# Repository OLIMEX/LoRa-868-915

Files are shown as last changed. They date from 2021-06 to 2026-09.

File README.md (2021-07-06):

# LoRa868 / LoRa915 / MOD-LoRa868 / MOD-LoRa915

LoRa modules with SX1276 modem from Semtech.

Product page: https://www.olimex.com/Products/IoT/LoRa/LoRa868/open-source-hardware

Product page: https://www.olimex.com/Products/IoT/LoRa/LoRa915/open-source-hardware

Product page: https://www.olimex.com/Products/IoT/LoRa/MOD-LoRa868/open-source-hardware

Product page: https://www.olimex.com/Products/IoT/LoRa/MOD-LoRa915/open-source-hardware

## License
* Hardware design is released under CERN OHL v1.2 license
* Software is released under GPL3 License
* Documentation is released under CC BY-SA 3.0

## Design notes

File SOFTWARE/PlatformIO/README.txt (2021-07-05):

Demo project for 2xMOD-LORA and 2xOlimexino-2560 made for PlatformIO environment with Arduino plugin.

Load the whole folder "LoRaPingPong" in PlatformIO, remember to edit platformio.ini to fit your USB port and board.

The code will ping-pong data between at least two boards. Refer to main.cpp.

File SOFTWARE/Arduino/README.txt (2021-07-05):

The Olimex LoRa board had been tested successfully with the Arduino library "LoRa" by Sandeep Mistry, just find it and install it from the Arduino library manager. Refer to the picture in this folder.

Other libraries and software that support the SX1276 chip should work well with the boards too.

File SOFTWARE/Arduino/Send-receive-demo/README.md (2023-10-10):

Demo software for Olimex MOD-LoRa868-ANT/MOD-LoRa868-EANT and Olimex ESP32-EVB

Demo uses sandeepmistry's LoRa library and examples:

https://github.com/sandeepmistry/arduino-LoRa

Configuration for ESP32-EVB comes with ESP32 package for Arduino:

https://github.com/espressif/arduino-esp32

Required hardware:

- Two (2) MOD-LoRa868-ANT/MOD-LoRa868-EANT modules

- Two (2) ESP32-EVB boards

- Two (2) micro USB cables

Remember LoRa modules would NOT work without an external antenna!

Required software:

- Arduino IDE, get it from here:

https://www.arduino.cc/en/software

- ESP32 package for Arduino IDE, install it following this advice:

https://espressif-docs.readthedocs-hosted.com/projects/arduino-esp32/en/latest/installing.html

- Arduino LoRa library by Sandeep Mistry, install following the advice here:

https://github.com/OLIMEX/LoRa-868-915/tree/main/SOFTWARE/Arduino

Once set, remember to select Olimex ESP32-EVB from board selector and the COM port where 
the board is located.

Each MOD-LoRa868 gets connected directly to the UEXT of each of the 
ESP32-EVB boards. One couple gets programmed with LoRaSender.ino,
the other with - LoRaReceiver.ino.

Connect both boards to free USB ports.

Open serial terminal software (like PuTTY) on each board's virtual COM port. Baud is 115200.

One board sends hello packets in a 1 second interval. 

The other receives packets "hello #number" and reports signal strength.

Refer to picture test.ping.

The demo can be used with MOD-LoRa915-ANT or other boards with SPI:

- If you decide to use MOD-LoRa915-ANT instead, you need to edit the code,
change LoRa.begin(868E6) to LoRa.begin(915E6) in both .ino files.

- If you decide to use another board that has free SPI make sure to change
defines at start so that it corresponds to your board; notice that
if MISO, MOSI, CLK are different to what is defined for your board
you might need to edit the library.

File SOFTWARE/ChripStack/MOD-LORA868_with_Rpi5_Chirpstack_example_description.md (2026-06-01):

# MOD-LORA868 + ChirpStack Demo Guide

## Overview

This guide demonstrates a complete LoRaWAN uplink/downlink test using an **Olimex MOD-LORA868** node and a **ChirpStack** network server running on a **Raspberry Pi 5** with an **LR1302 Gateway HAT (868 MHz)**.

The gateway image comes pre-configured with ChirpStack, a device profile (LoRaWAN 1.1.0, ABP, Class A, EU868, RP002-1.0.5), and matching ABP keys — so you can focus on the node side and start testing right away.

## Hardware Required

**Gateway side:**
- Raspberry Pi 5
- LR1302 LoRa Gateway HAT (868 MHz) — with its 868 MHz antenna
- MicroSD card (8 GB or larger)
- Ethernet cable (for network access)

**Node side:**
- ESP32-C6-DevKit-LiPo
- MOD-LORA868 (plugged into the UEXT connector)
- 868 MHz antenna for MOD-LORA868
- USB-C cable

> **⚠️ Important:** Always attach the 868 MHz antenna to MOD-LORA868 before powering on. Transmitting without an antenna can damage the RF stage.

## Gateway Setup

1. Download `rpi_chirpstack_lora_868_example.zip` from here: https://ftp.olimex.com/LoRa/rpi_chirpstack_lora_868_example.zip and extract the image file.
2. Write the image to a MicroSD card using [Raspberry Pi Imager](https://www.raspberrypi.com/software/) or [balenaEtcher](https://etcher.balena.io/).
3. Mount the LR1302 Gateway HAT on the Raspberry Pi 5 and connect its 868 MHz antenna.
4. Insert the MicroSD card and connect the Pi to your local network via Ethernet.
5. Power on the Raspberry Pi and wait about a minute for all services to start.

**Accessing the gateway:**

- **SSH:** `ssh olimex@olimexpi.local` (password: `olimex`)
- **ChirpStack Web UI:** open [http://olimexpi.local:8080/](http://olimexpi.local:8080/) in a browser (login: `admin` / `admin`)

The image comes with the gateway, device profile, and a test device already configured — no additional ChirpStack setup is needed.

## Node Firmware Setup

### Requirements

- Arduino IDE 2.3.7 (or compatible)
- ESP32 board package installed (with ESP32-C6 support)
- [RadioLib](https://github.com/jgromes/RadioLib) library v7.5.0

### Board Settings

In Arduino IDE, select:

- **Board:** ESP32C6 Dev Module
- **USB CDC On Boot:** Disabled
- All other settings can remain at their defaults.

### Upload

1. Plug MOD-LORA868 into the UEXT connector on the ESP32-C6-DevKit-LiPo.
2. Attach a 868 MHz antenna to MOD-LORA868.
3. Connect the board to your PC via the USB-C port labeled **USB-UART1** — this is also where the Serial Monitor output will appear.
4. Open the sketch in Arduino IDE, compile and upload.
5. Open Serial Monitor at **115200 baud**.

## Running the Test

After upload you should see:

```
START
Initializing radio... OK

╔════════════════════════════════════════╗
║      MOD-LORA868 Test v1.2             ║
╚════════════════════════════════════════╝
  Mode: ABP (no Join)
  NVS persistence: ENABLED
  Press ENTER or button to run test
  Type 'R' + ENTER to reset session
```

Press **ENTER** in the Serial Monitor (or press the button on the board) to send a confirmed uplink. A successful round-trip looks like this:

```
========================================
  TEST #1
========================================
Sending confirmed uplink... OK
ACK received in RX window: 1
RSSI: -55.00 dBm
SNR:  9.25 dB
========================================

  ✅ ✅ ✅  SUCCESS  ✅ ✅ ✅
  Board passed the test!
  UPLINK:   OK
  DOWNLINK: OK (ACK received)

========================================
```

You can repeat the test as many times as needed. The frame counter is saved in NVS and persists across reboots.

**Resetting the session:** if the frame counter gets out of sync with ChirpStack (e.g. after re-flashing the device in ChirpStack), type `R` + ENTER in the Serial Monitor to clear the saved session, then restart the board.

## Verifying in ChirpStack

Open [http://olimexpi.local:8080/](http://olimexpi.local:8080/) and navigate to the pre-configured device. Under the **Events** tab you should see the incoming uplinks with the `TEST` payload and the corresponding downlink ACKs.

## Troubleshooting

| Symptom | Possible Cause |
|---|---|
| `CRITICAL ERROR: Radio failed to initialize!` | MOD-LORA868 not seated properly in UEXT connector; check SPI wiring |
| `Waiting for ACK... TIMEOUT` | Gateway not running or out of range; check antenna connections on both sides; verify ChirpStack is active (`ssh` in and run `sudo docker ps`) |
| Frame counter errors in ChirpStack | Session out of sync — type `R` + ENTER to reset, then restart the board |
| `olimexpi.local` not resolving | Connect via IP instead; check that the Pi is on the same network |

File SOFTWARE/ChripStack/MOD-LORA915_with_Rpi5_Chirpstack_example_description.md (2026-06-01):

# MOD-LORA915 + ChirpStack Demo Guide

## Overview

This guide demonstrates a complete LoRaWAN uplink/downlink test using an **Olimex MOD-LORA915** node and a **ChirpStack** network server running on a **Raspberry Pi 5** with an **LR1302 Gateway HAT (915 MHz)**.

The gateway image comes pre-configured with ChirpStack, a device profile (LoRaWAN 1.0.4, ABP, Class A, US915), and matching ABP keys — so you can focus on the node side and start testing right away.

## Hardware Required

**Gateway side:**
- Raspberry Pi 5
- LR1302 LoRa Gateway HAT (915 MHz) — with its 915 MHz antenna
- MicroSD card (8 GB or larger)
- Ethernet cable (for network access)

**Node side:**
- ESP32-C6-DevKit-LiPo
- MOD-LORA915 (plugged into the UEXT connector)
- 915 MHz antenna for MOD-LORA915
- USB-C cable

> **⚠️ Important:** Always attach the 915 MHz antenna to MOD-LORA915 before powering on. Transmitting without an antenna can damage the RF stage.

## Gateway Setup

1. Download `rpi_chirpstack_lora_915_example.zip` from here: https://ftp.olimex.com/LoRa/rpi_chirpstack_lora_915_example.zip and extract the image file.
2. Write the image to a MicroSD card using for example [balenaEtcher](https://etcher.balena.io/).
3. Mount the LR1302 Gateway HAT on the Raspberry Pi 5 and connect its 915 MHz antenna.
4. Insert the MicroSD card and connect the Pi to your local network via Ethernet.
5. Power on the Raspberry Pi and wait about a minute for all services to start.

**Accessing the gateway:**

- **SSH:** `ssh olimex@olimexpi.local` (password: `olimex`)
- **ChirpStack Web UI:** open [http://olimexpi.local:8080/](http://olimexpi.local:8080/) in a browser (login: `admin` / `admin`)

The image comes with the gateway, device profile, and a test device already configured — no additional ChirpStack setup is needed.

## Node Firmware Setup

### Requirements

- Arduino IDE 2.3.7 (or compatible)
- ESP32 board package installed (with ESP32-C6 support)
- [RadioLib](https://github.com/jgromes/RadioLib) library v7.5.0

### Board Settings

In Arduino IDE, select:

- **Board:** ESP32C6 Dev Module
- **USB CDC On Boot:** Disabled
- All other settings can remain at their defaults.

### Upload

1. Plug MOD-LORA915 into the UEXT connector on the ESP32-C6-DevKit-LiPo.
2. Attach a 915 MHz antenna to MOD-LORA915.
3. Connect the board to your PC via the USB-C port labeled **USB-UART1** — this is also where the Serial Monitor output will appear.
4. Open the sketch in Arduino IDE, compile and upload.
5. Open Serial Monitor at **115200 baud**.

## Running the Test

After upload you should see:

```
START
Initializing radio... OK

╔════════════════════════════════════════╗
║      MOD-LORA915 Test v1.1             ║
╚════════════════════════════════════════╝
  Mode: ABP (no Join)
  NVS persistence: ENABLED
  Press ENTER or button to run test
  Type 'R' + ENTER to reset session
```

Press **ENTER** in the Serial Monitor (or press the button on the board) to send a confirmed uplink. A successful round-trip looks like this:

```
========================================
  TEST #1
========================================
Sending confirmed uplink... OK
ACK received in RX window: 2
RSSI: -62.00 dBm
SNR:  8.50 dB
========================================

  ✅ ✅ ✅  SUCCESS  ✅ ✅ ✅
  Board passed the test!
  UPLINK:   OK
  DOWNLINK: OK (ACK received)

========================================
```

You can repeat the test as many times as needed. The frame counter is saved in NVS and persists across reboots.

**Resetting the session:** if the frame counter gets out of sync with ChirpStack (e.g. after re-flashing the device in ChirpStack), type `R` + ENTER in the Serial Monitor to clear the saved session, then restart the board.

## Verifying in ChirpStack

Open [http://olimexpi.local:8080/](http://olimexpi.local:8080/) and navigate to the pre-configured device. Under the **Events** tab you should see the incoming uplinks with the `TEST` payload and the corresponding downlink ACKs.

## Troubleshooting

| Symptom | Possible Cause |
|---|---|
| `CRITICAL ERROR: Radio failed to initialize!` | MOD-LORA915 not seated properly in UEXT connector; check SPI wiring |
| `Waiting for ACK... TIMEOUT` | Gateway not running or out of range; check antenna connections on both sides; verify ChirpStack is active (`ssh` in and run `sudo docker ps`) |
| Frame counter errors in ChirpStack | Session out of sync — type `R` + ENTER to reset, then restart the board |
| `olimexpi.local` not resolving | Connect via IP instead; check that the Pi is on the same network |

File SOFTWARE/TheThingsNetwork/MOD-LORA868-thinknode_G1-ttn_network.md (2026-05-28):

# MOD-LORA868 + The Things Network (TTN) Guide

## Overview

This guide demonstrates a complete LoRaWAN uplink/downlink test using an **Olimex MOD-LORA868** node connected to **The Things Network (TTN)** via any TTN-compatible EU868 gateway.

The same Arduino sketch used with a local ChirpStack setup works with TTN without any code changes — you only need to update the ABP keys to match your TTN device configuration.

## Hardware Required

- ESP32-C6-DevKit-LiPo
- MOD-LORA868 (plugged into the UEXT connector)
- 868 MHz antenna for MOD-LORA868
- USB-C cable
- A TTN-compatible EU868 gateway (e.g. ThinkNode G1) within range, registered and connected to TTN

> **⚠️ Important:** Always attach the 868 MHz antenna to MOD-LORA868 before powering on. Transmitting without an antenna can damage the RF stage.

## TTN Setup

### 1. Create an Account

Register at [https://www.thethingsnetwork.org/](https://www.thethingsnetwork.org/) if you don't already have an account.

### 2. Make Sure You Have a Gateway

You need a TTN-compatible EU868 gateway registered and online in your area. Gateway registration and setup are covered in your gateway's documentation and in the [TTN documentation](https://www.thethingsindustries.com/docs/gateways/).

### 3. Create an Application

1. Open the TTN Console: [https://eu1.cloud.thethings.network/console/](https://eu1.cloud.thethings.network/console/)
2. Go to **Applications** → **+ Create application**
3. Enter an Application ID (e.g. `mod-lora868-abp`) and click **Create application**

### 4. Register the Device

1. Inside your application, go to **End devices** → **+ Register end device**
2. Select **Enter end device specifics manually**
3. Configure as follows:
   - **Frequency plan:** Europe 863-870 MHz (SF9 for RX2 - recommended)
   - **LoRaWAN version:** LoRaWAN Specification 1.1.0
   - **Regional Parameters version:** RP002 Regional Parameters 1.0.4
   - **Activation mode:** ABP (Activation by Personalization)
4. Generate or enter the **DevEUI**, then click **Register end device**
5. After registration, go to the device page. Under **Session information** you will find:
   - **Device address**
   - **FNwkSIntKey** / **SNwkSIntKey** / **NwkSEncKey**
   - **AppSKey**

### 5. Update the Arduino Sketch

Copy the keys from TTN into the sketch, replacing the placeholder values:

```cpp
uint32_t devAddr     = 0x260be6c4;
uint8_t nwkSEncKey[] = {0x60, 0xCA, 0xCF, 0xAF, 0x55, 0xCD, 0x12, 0x63,
                         0x62, 0xF8, 0x20, 0x41, 0x61, 0xEE, 0x27, 0xA3};
uint8_t appSKey[]    = {0xDA, 0x15, 0xD8, 0x81, 0x86, 0x92, 0xBD, 0xEE,
                         0xB8, 0xBD, 0x5F, 0xFE, 0xEE, 0xDE, 0x10, 0x31};
```

In TTN, **FNwkSIntKey**, **SNwkSIntKey**, and **NwkSEncKey** are all the same key for ABP devices — this matches the sketch where `nwkSEncKey` is passed for all three parameters in the `beginABP()` call.

## Node Firmware Setup

### Requirements

- Arduino IDE 2.3.7 (or compatible)
- ESP32 board package installed (with ESP32-C6 support)
- [RadioLib](https://github.com/jgromes/RadioLib) library v7.5.0

### Board Settings

In Arduino IDE, select:

- **Board:** ESP32C6 Dev Module
- **USB CDC On Boot:** Disabled
- All other settings can remain at their defaults.

### Upload

1. Plug MOD-LORA868 into the UEXT connector on the ESP32-C6-DevKit-LiPo.
2. Attach a 868 MHz antenna to MOD-LORA868.
3. Connect the board to your PC via the USB-C port labeled **USB-UART1** — this is also where the Serial Monitor output will appear.
4. Open the sketch in Arduino IDE, compile and upload.
5. Open Serial Monitor at **115200 baud**.

## Running the Test

After upload you should see:

```
START
Initializing radio... OK

╔════════════════════════════════════════╗
║      MOD-LORA868 Test v1.2             ║
╚════════════════════════════════════════╝
  Mode: ABP (no Join)
  NVS persistence: ENABLED
  Press ENTER or button to run test
  Type 'R' + ENTER to reset session
```

Press **ENTER** in the Serial Monitor (or press the button on the board) to send a confirmed uplink. A successful round-trip looks like this:

```
========================================
  TEST #1
========================================
Sending confirmed uplink... OK
ACK received in RX window: 1
RSSI: -55.00 dBm
SNR:  9.25 dB
========================================

  ✅ ✅ ✅  SUCCESS  ✅ ✅ ✅
  Board passed the test!
  UPLINK:   OK
  DOWNLINK: OK (ACK received)

========================================
```

You can repeat the test as many times as needed. The frame counter is saved in NVS and persists across reboots.

**Resetting the session:** if the frame counter gets out of sync with TTN (e.g. after re-registering the device), type `R` + ENTER in the Serial Monitor to clear the saved session, then restart the board.

## Verifying in TTN

Open the TTN Console, navigate to your application and device. Under the **Live data** tab you should see the incoming uplinks with the `TEST` payload and the corresponding downlink ACKs.

## Troubleshooting

| Symptom | Possible Cause |
|---|---|
| `CRITICAL ERROR: Radio failed to initialize!` | MOD-LORA868 not seated properly in UEXT connector; check SPI wiring |
| `Waiting for ACK... TIMEOUT` | No gateway in range, or gateway not connected to TTN; check antenna connections; verify gateway status in TTN Console |
| Frame counter errors in TTN | Session out of sync — type `R` + ENTER to reset, then restart the board. In TTN you may also need to reset the device session from the device page. |
| Uplink appears in TTN but no ACK | Check that confirmed downlinks are not blocked by fair use policy; TTN has a daily downlink limit |

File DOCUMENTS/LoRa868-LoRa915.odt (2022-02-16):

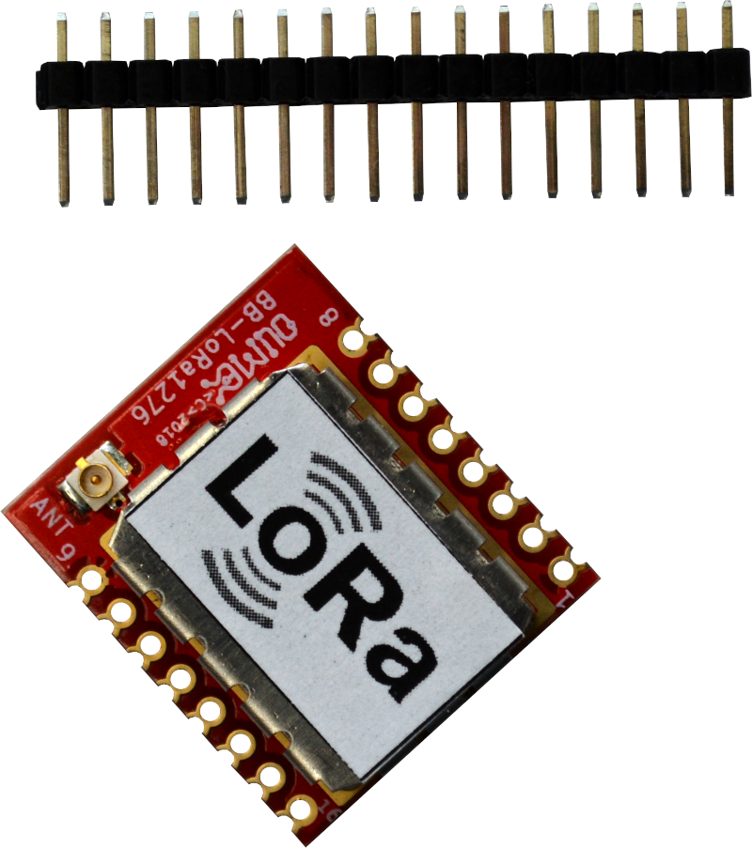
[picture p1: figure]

LoRa868 – LoRa915

User Manual

Document revision 2.0 February 2022

olimex.com

# Overview

LoRa (short from long range) is a spread spectrum modulation technique derived from chirp spread spectrum (CSS) technology. LoRa devices and wireless radio frequency technology is a long range, low power wireless platform that has become very popular for Internet of Things (IoT) networks worldwide. LoRa devices and the open LoRaWAN® protocol enable smart IoT applications that solve some of the biggest challenges our planet faces: energy management, natural resource reduction, pollution control, infrastructure efficiency, disaster prevention, and more.

LoRa advantages are:

- Easy to install – wireless technology, no need to install wires, dig channels etc.
- Uses license free frequency – no need to pay licensee fees like GSM frequencies.
- Low power – LoRa devices can work up to 10 years on a small lithium battery (depends on how many messages per day device will send).
- Long Range – LoRa devices can communicate up to 15 km at rural and up to 1-2km in urban area.
- Secure communication – all messages are AES128 encrypted.
- Low Cost – LoRa devices are usually under EUR 10.
- No taxes for traffic unlike other technologies which require operator (GSM, LTE, NB-IoT, SigFox etc).

LoRa is not the answer to all problems, it comes with some limitations:

- small messages 51 up to 222 bytes
- slow speed of transmission 292 up to 550 bps

The long range is good but also bad as when one device starts to transmit all other devices in its range can’t transmit. This creates some issues when for instance thousands of devices are installed in their transmission range reach. When we add to this that there is no moderation/operator who to set rules, if one participant do not follow the rules and start to transmit without pause this participant will jam/silence all others withing his transmission ranges.

## General Information

The core of LoRa868 (https://www.olimex.com/Products/IoT/LoRa/LoRa868/open-source-hardware) / LoRa (https://www.olimex.com/Products/IoT/LoRa/LoRa915/open-source-hardware)915 (https://www.olimex.com/Products/IoT/LoRa/LoRa915/open-source-hardware) is Semtech's SX1276 (https://www.semtech.com/products/wireless-rf/lora-core/sx1276) transciever.

The interface to host microcontroller is via SPI interface with up to 10Mhz SCK.

SX1276 takes care for all details for the modulation, encryption and etc.

RF front end is with 168 dB maximum link budget, which allow communication even in harsh environments.

Low RX current of 10 mA and 200 nA register retention in deep sleep.

SX1276 has built-in temperature sensor and low battery indicator.

LoRa868 and LoRa915 have no antenna by default, they have u.FL connector where external antenna must be connected. 16 pin header is provided if customer wants to solder and use on breadboard.

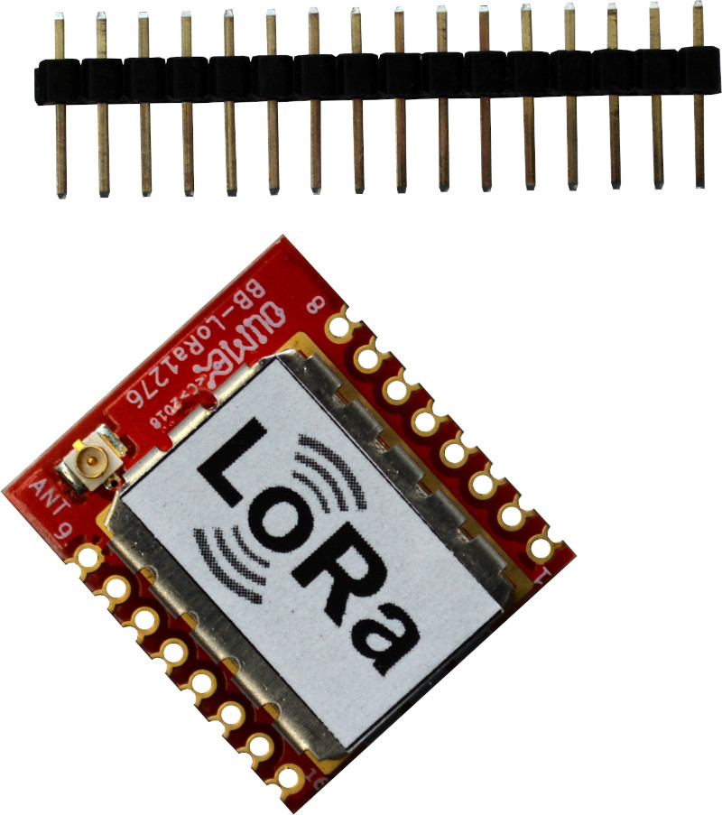
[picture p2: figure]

For LoRa868 and LoRa915 we do offer PCB antenna with +2dBi gain :

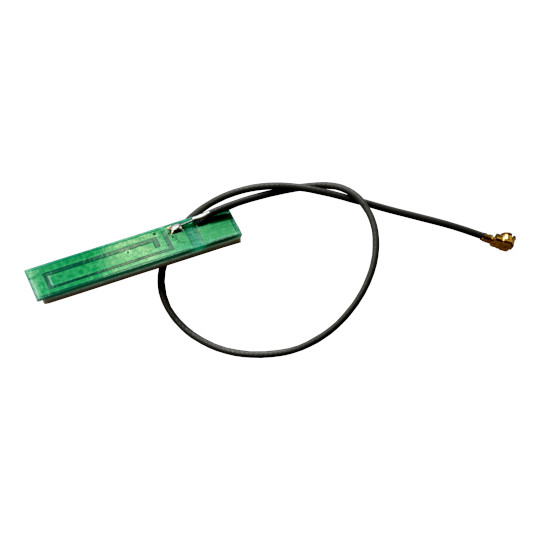
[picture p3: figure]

LoRa868-ANT and LoRa915-ANT includes this antenna.

For LoRa868 we offer also +3dBi duck antenna:

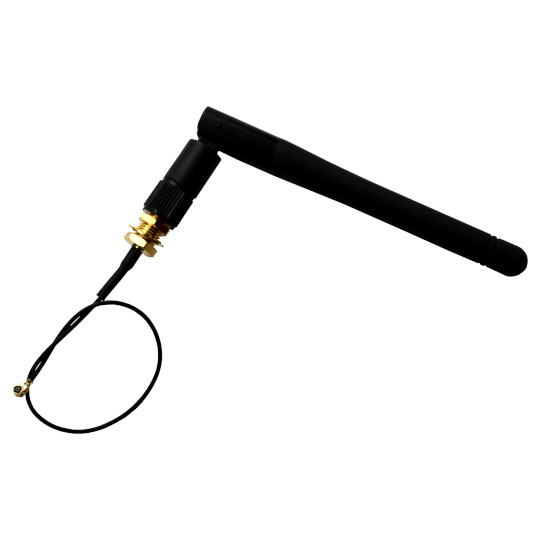
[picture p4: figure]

LoRa868-EANT includes this antenna. We do not offer duck antenna for LoRa915.

## Order Codes

LoRa in Europe operates at 868Mz and in North America operates at 915Mhz. Please make sure you select the proper LoRa module for your region.

(https://www.olimex.com/Products/IoT/LoRa/LoRa868/open-source-hardware)

LoRa868 (https://www.olimex.com/Products/IoT/LoRa/LoRa868/open-source-hardware) industrial grade -40+85°C, European frequency, no antenna, u.FL IPEX connector

LoRa868 (https://www.olimex.com/Products/IoT/LoRa/LoRa868/open-source-hardware)- (https://www.olimex.com/Products/IoT/LoRa/LoRa868-ANT/open-source-hardware)ANT (https://www.olimex.com/Products/IoT/LoRa/LoRa868-ANT/open-source-hardware) industrial grade -40+85°C, European frequency, includes cable and PCB antenna

LoRa868- (https://www.olimex.com/Products/IoT/LoRa/MOD-LoRa868-EANT/open-source-hardware)EANT (https://www.olimex.com/Products/IoT/LoRa/MOD-LoRa868-EANT/open-source-hardware) industrial grade -40+85°C, European frequency, includes cable and external duck antenna +3dBi

LoRa (https://www.olimex.com/Products/IoT/LoRa/MOD-LoRa915/open-source-hardware)915 (https://www.olimex.com/Products/IoT/LoRa/MOD-LoRa915/open-source-hardware) industrial grade -40+85°C, North American frequency, no antenna, u.FL IPEX connector

LoRa (https://www.olimex.com/Products/IoT/LoRa/MOD-LoRa915-ANT/open-source-hardware)915 (https://www.olimex.com/Products/IoT/LoRa/MOD-LoRa915-ANT/open-source-hardware)- (https://www.olimex.com/Products/IoT/LoRa/MOD-LoRa915-ANT/open-source-hardware)ANT (https://www.olimex.com/Products/IoT/LoRa/MOD-LoRa915-ANT/open-source-hardware) industrial grade -40+85°C, North American frequency, includes cable and PCB antenna

# Software

SX1276 is a mature chip and has good software support.

Libraries for direct LoRa modulation and for LoRaWAN stack are available for different processors.

Note that the Chinese clones of SX1276 like RFM95W have a bug in low data rate optimization flag settings and high power mode, due to the popularity of these clones all default Arduino libraries for LoRa has wrong setup to work around the RFM95W bug. We recommend to use the libraries and examples from our web.

# Power Supply

LoRa868/915 supply voltage is 3.3V, but operates from 1.8 up to 3.7VDC, this allow full utilization of LiPo 3.7V battery (discharged 2.0V, charged 3.7V)

Make sure your power source can provide peak current at least 120mA.

Power consumption is:

- Supply current in Sleep mode 0.2mA
- Supply current in Standby mode 1.6-1.8mA
- Supply current in Receive mode 10-12mA
- Supply current in Transmit mode +13 dBm 29 mA
- Supply current in Transmit mode +20 dBm 120 mA

# Pinout

All SX1276 signals are available on two 0.1 inch (2.54 mm) step row of 8 pads where headers can be soldered.

The distance between the rows is 0.8 inch (20.32mm)

There is second cut through row of pads which is spaced at 0.05 inch (1.27mm), so the distance between these two rows is 0.9 inch (22.86 mm).

Total board dimensions are 0.9 inch (22.86 mm) x 1.023 inch (26 mm)

These cut through pads are convenient to solder LoRa868/915 module directly on main PCB.

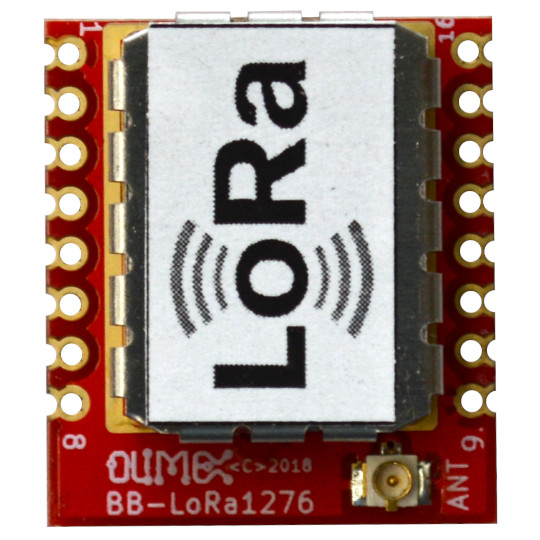
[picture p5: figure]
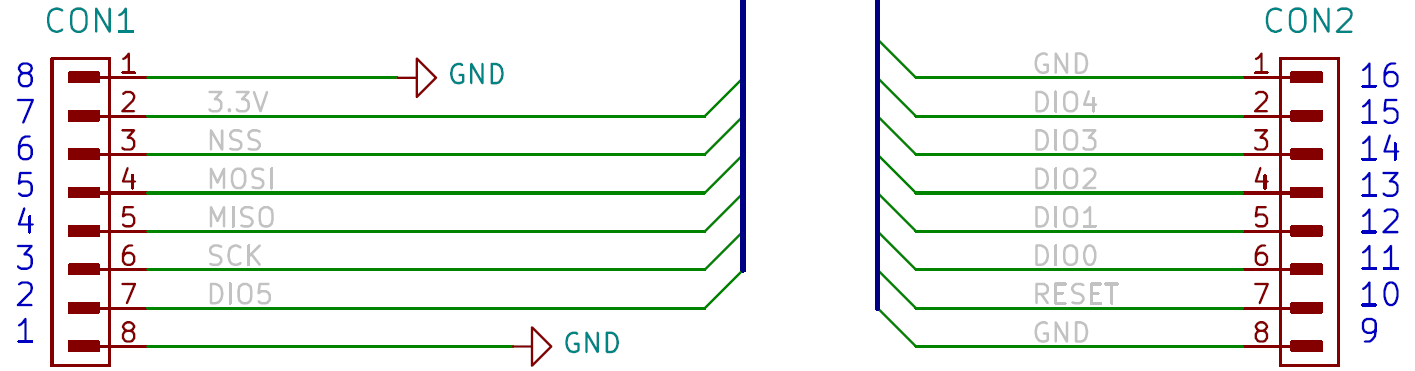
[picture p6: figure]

# Open Source Hardware Design

LoRa868 / LoRa915 is open source hardware, this means that all CAD sources are available and free to be learn, study, modify, distribute, make, and sell the design or hardware based on that design.

The board is designed using KiCad.

KiCad (https://www.kicad.org/) is open source software and completely free to download and use.

All files are available on GitHub (https://github.com/OLIMEX/LoRa-868-915).

# Revision History

Revision 2.0 February 2022

- fixed wrong CON1 labeling in schematic

Revision 1.0 May 2021

# Contact Information

Headquarters and Factory address:

OLIMEX Ltd

ul. Pravda 2

Plovdiv 4000

BULGARIA

Sales: sales@olimex.com

Technical Support: support@olimex.com

Corporate Website: www.olimex.com

For latest news and developments – follow our

- Blog (https://olimex.wordpress.com/)
- GitHub (https://github.com/OLIMEX)
- Twitter (https://twitter.com/olimex)
- Facebook (https://www.facebook.com/OLINUXINO/)
- Mastodon (https://mastodon.social/@olimex)
- Pluspora (https://pluspora.com/people/604855503b7f01377c23005056264835)
- IRC (https://webchat.freenode.net/#olimex)
- flicr (https://www.flickr.com/photos/olimex/)

12 LoRa868 / LoRa915 Rev 2.0 www.olimex.com

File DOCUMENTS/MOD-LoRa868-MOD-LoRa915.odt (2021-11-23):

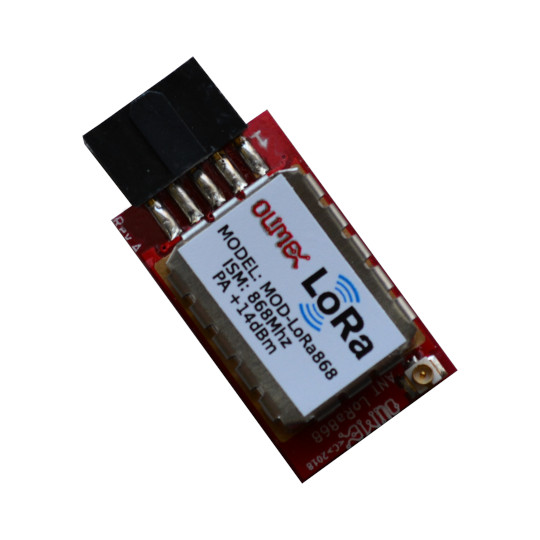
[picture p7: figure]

MOD-LoRa868

MOD-LoRa915

User Manual

Rev.1.0 June 2021

olimex.com

# Overview

LoRa (short for long range) is a spread spectrum modulation technique derived from chirp spread spectrum (CSS) technology. LoRa devices and wireless radio frequency technology is a long range, low power wireless platform that has become very popular for Internet of Things (IoT) networks worldwide. LoRa devices and the open LoRaWAN® protocol enable smart IoT applications that solve some of the biggest challenges facing our planet: energy management, natural resource reduction, pollution control, infrastructure efficiency, disaster prevention, and more.

LoRa advantages are:

- Easy to install – wireless technology, no need to install wires, dig channels etc.
- Uses license free frequancy – no need to pay licensee fees like GSM frequencies.
- Low power – LoRa devices can work up to 10 years from small lithium battery (depend on how many messages per day device will send).
- Long Range – LoRa devices can communicate up to 15 km at rural and up to 1-2km in urban area.
- Secure communication – all messages are AES128 encrypted
- Low Cost – LoRa devices are under EUR 10
- No taxes for traffic like other technologies which require operator like GSM, LTE, NB-IoT, SigFox etc.

LoRa is not solution for any problem, some limitations are:

- small messages 51 up to 222 bytes
- slow speed of transmission 292 up to 550 bps

The long range is good but also bad as when one device start to transmit all other devices in it’s range can’t transmit. This creates some issues when for instance thousands of devices are installed in their transmission range reach. When we add to this that there is no moderation/operator who to set rules, if one participant do not follow the rules and start to transmit without pause this participant will jam/silence all others withing his transmission ranges.

## General information

The core of MOD- (https://www.olimex.com/Products/IoT/LoRa/MOD-LoRa868/open-source-hardware)LoRa868 (https://www.olimex.com/Products/IoT/LoRa/MOD-LoRa868/open-source-hardware) / MOD- (https://www.olimex.com/Products/IoT/LoRa/MOD-LoRa915/open-source-hardware)LoRa (https://www.olimex.com/Products/IoT/LoRa/MOD-LoRa915/open-source-hardware)915 (https://www.olimex.com/Products/IoT/LoRa/MOD-LoRa915/open-source-hardware) is Semtech's SX1276 (https://www.semtech.com/products/wireless-rf/lora-core/sx1276) transciever.

The interface to host microcontroller is via SPI interface with up to 10Mhz SCK.

SX1276 takes care for all details for the modulation, encryption and etc.

RF front end is with 168 dB maximum link budget, which allow communication even in harsh environments.

Low RX current of 10 mA and 200 nA register retention in deep sleep.

SX1276 has built-in temperature sensor and low battery indicator.

LoRa868 and LoRa915 have no antenna by default, they have u.FL connector where external antenna must be connected. 16 pin header is provided if customer wants to solder and use on breadboard.

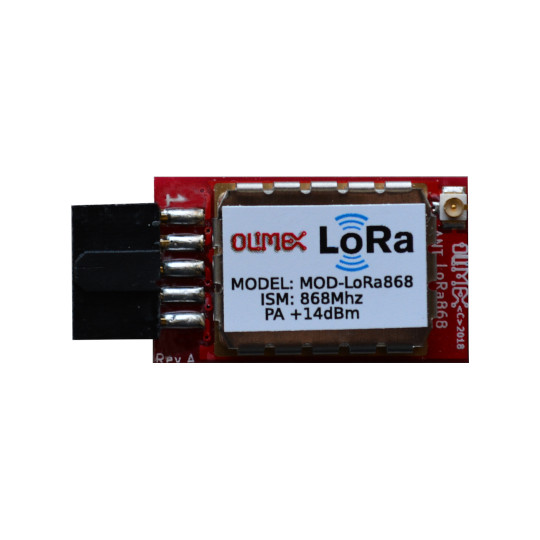
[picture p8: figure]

For MOD- (https://www.olimex.com/Products/IoT/LoRa/MOD-LoRa868/open-source-hardware)LoRa868 (https://www.olimex.com/Products/IoT/LoRa/MOD-LoRa868/open-source-hardware) and MOD- (https://www.olimex.com/Products/IoT/LoRa/MOD-LoRa915/open-source-hardware)LoRa (https://www.olimex.com/Products/IoT/LoRa/MOD-LoRa915/open-source-hardware)915 (https://www.olimex.com/Products/IoT/LoRa/MOD-LoRa915/open-source-hardware) we do offer PCB antenna with +2dBi gain :


MOD- (https://www.olimex.com/Products/IoT/LoRa/MOD-LoRa868-ANT/open-source-hardware)LoRa868-ANT (https://www.olimex.com/Products/IoT/LoRa/MOD-LoRa868-ANT/open-source-hardware) and MOD- (https://www.olimex.com/Products/IoT/LoRa/MOD-LoRa915-ANT/open-source-hardware)LoRa915-ANT (https://www.olimex.com/Products/IoT/LoRa/MOD-LoRa915-ANT/open-source-hardware) includes this antenna.

For MOD- (https://www.olimex.com/Products/IoT/LoRa/MOD-LoRa868/open-source-hardware)LoRa868 (https://www.olimex.com/Products/IoT/LoRa/MOD-LoRa868/open-source-hardware) we offer also +3dBi duck antenna:


MOD- (https://www.olimex.com/Products/IoT/LoRa/MOD-LoRa868-EANT/open-source-hardware)LoRa868-EANT (https://www.olimex.com/Products/IoT/LoRa/MOD-LoRa868-EANT/open-source-hardware) includes this antenna. We do not offer duck antenna for MOD- (https://www.olimex.com/Products/IoT/LoRa/MOD-LoRa915/open-source-hardware)LoRa (https://www.olimex.com/Products/IoT/LoRa/MOD-LoRa915/open-source-hardware)915 (https://www.olimex.com/Products/IoT/LoRa/MOD-LoRa915/open-source-hardware).

## Order codes

LoRa in Europe operates at 868Mz and in North America operates at 915Mhz. Please make sure you select the proper LoRa module for your region.

(https://www.olimex.com/Products/IoT/LoRa/LoRa868/open-source-hardware)

MOD- (https://www.olimex.com/Products/IoT/LoRa/MOD-LoRa868/open-source-hardware)LoRa868 (https://www.olimex.com/Products/IoT/LoRa/MOD-LoRa868/open-source-hardware) industrial grade -40+85°C, European frequency, no antenna, u.FL IPEX connector

MOD- (https://www.olimex.com/Products/IoT/LoRa/MOD-LoRa868-ANT/open-source-hardware)LoRa868- (https://www.olimex.com/Products/IoT/LoRa/MOD-LoRa868-ANT/open-source-hardware)ANT (https://www.olimex.com/Products/IoT/LoRa/MOD-LoRa868-ANT/open-source-hardware) industrial grade -40+85°C, European frequency, includes cable and PCB antenna

MOD- (https://www.olimex.com/Products/IoT/LoRa/MOD-LoRa868-EANT/open-source-hardware)LoRa868- (https://www.olimex.com/Products/IoT/LoRa/MOD-LoRa868-EANT/open-source-hardware)EANT (https://www.olimex.com/Products/IoT/LoRa/MOD-LoRa868-EANT/open-source-hardware) industrial grade -40+85°C, European frequency, includes cable and external duck antenna +3dBi

MOD- (https://www.olimex.com/Products/IoT/LoRa/MOD-LoRa915/open-source-hardware)LoRa (https://www.olimex.com/Products/IoT/LoRa/MOD-LoRa915/open-source-hardware)915 (https://www.olimex.com/Products/IoT/LoRa/MOD-LoRa915/open-source-hardware) industrial grade -40+85°C, North American frequency, no antenna, u.FL IPEX connector

MOD- (https://www.olimex.com/Products/IoT/LoRa/MOD-LoRa915-ANT/open-source-hardware)LoRa (https://www.olimex.com/Products/IoT/LoRa/MOD-LoRa915-ANT/open-source-hardware)915 (https://www.olimex.com/Products/IoT/LoRa/MOD-LoRa915-ANT/open-source-hardware)- (https://www.olimex.com/Products/IoT/LoRa/MOD-LoRa915-ANT/open-source-hardware)ANT (https://www.olimex.com/Products/IoT/LoRa/MOD-LoRa915-ANT/open-source-hardware) industrial grade -40+85°C, North American frequency, includes cable and PCB antenna

# Software

SX1276 is mature chip and has good software support.

Libraries for direct LoRa modulation and for LoRaWAN stack are available for different processors.

Note that the Chinese clones of SX1276 like RFM95W have bug in low data rate optimization flag settings and high power mode, due to the popularity of these clones all default Arduino libraries for LoRa has wrong setup to work around the RFM95W bug. We recommend to use the libraries and examples from our web.

# Power supply

MOD- (https://www.olimex.com/Products/IoT/LoRa/MOD-LoRa868/open-source-hardware)LoRa868 (https://www.olimex.com/Products/IoT/LoRa/MOD-LoRa868/open-source-hardware)/MOD-LoRa (https://www.olimex.com/Products/IoT/LoRa/MOD-LoRa915/open-source-hardware)915 (https://www.olimex.com/Products/IoT/LoRa/MOD-LoRa915/open-source-hardware) supply voltage is 3.3V, but can operate from 1.8 up to 3.7VDC, this allow full utilization of LiPo 3.7V battery (discharged 2.0V, charged 3.7V)

Make sure your power source can provide peak current at least 120mA.

Power consumption is:

- Supply current in Sleep mode 0.2mA
- Supply current in Standby mode 1.6-1.8mA
- Supply current in Receive mode 10-12mA
- Supply current in Transmit mode +13 dBm 29 mA
- Supply current in Transmit mode +20 dBm 120 mA

# Pinout

All SX1276 signals are available on two 0.1 inch (2.54 mm) step row of 8 pads where headers can be soldered.

MOD- (https://www.olimex.com/Products/IoT/LoRa/MOD-LoRa868/open-source-hardware)LoRa868 (https://www.olimex.com/Products/IoT/LoRa/MOD-LoRa868/open-source-hardware) / MOD-LoRa (https://www.olimex.com/Products/IoT/LoRa/MOD-LoRa915/open-source-hardware)915 (https://www.olimex.com/Products/IoT/LoRa/MOD-LoRa915/open-source-hardware) board dimensions are 1.24 inch (31.5 mm) x 0.73 inch (18.5 mm).

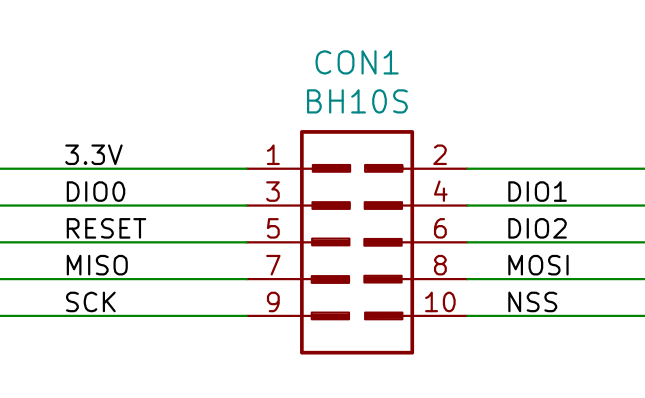
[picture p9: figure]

# Open Source Hardware design

MOD- (https://www.olimex.com/Products/IoT/LoRa/MOD-LoRa868/open-source-hardware)LoRa868 (https://www.olimex.com/Products/IoT/LoRa/MOD-LoRa868/open-source-hardware) / MOD-LoRa (https://www.olimex.com/Products/IoT/LoRa/MOD-LoRa915/open-source-hardware)915 (https://www.olimex.com/Products/IoT/LoRa/MOD-LoRa915/open-source-hardware) is open source hardware, this means that all CAD sources are available and free to be learn, study, modify, distribute, make, and sell the design or hardware based on that design.

The board is designed using KiCad.

KiCad (https://www.kicad.org/) is open source software and completely free to download and use.

All files are available on GitHub (https://github.com/OLIMEX/MOD-LoRa-868-915).

# Revision History

Revision 1.0 June 2021

# Contact information

Headquarters and Factory address:

OLIMEX Ltd

ul. Pravda 2

Plovdiv 4000

BULGARIA

Sales: sales@olimex.com

Technical Support: support@olimex.com

Corporate Website: www.olimex.com

For latest news and developments - follow our

- Blog (https://olimex.wordpress.com/)
- GitHub (https://github.com/OLIMEX)
- Twitter (https://twitter.com/olimex)
- Facebook (https://www.facebook.com/OLINUXINO/)
- Mastodon (https://mastodon.social/@olimex)
- Pluspora (https://pluspora.com/people/604855503b7f01377c23005056264835)
- IRC (https://webchat.freenode.net/#olimex)
- flicr (https://www.flickr.com/photos/olimex/)

12 MOD-LoRa868 / MOD-LoRa915 Rev 1.0 www.olimex.com

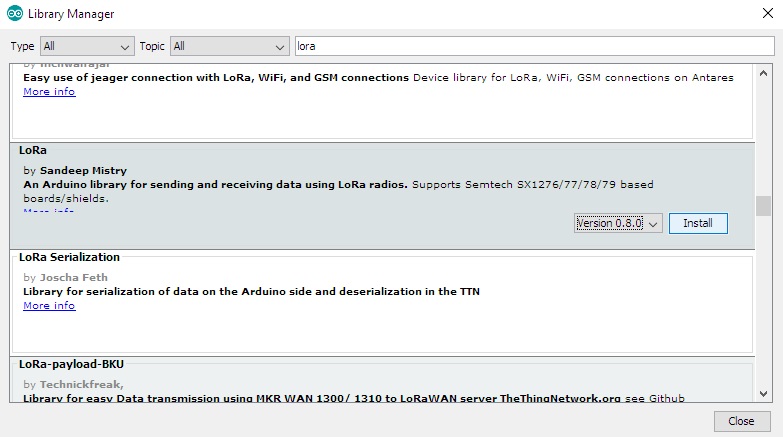
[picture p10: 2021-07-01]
SOFTWARE/Arduino/LoRa_Sandeep_Mistry.jpg

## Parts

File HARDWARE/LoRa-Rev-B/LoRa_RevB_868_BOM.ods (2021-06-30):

Designation | Quantity | Designator | Package
SMD ИНД 0402 10 nH LQP15MN10NG02D | 1 | L4 | L_0402_5MIL_DWS
SMD ИС SX1276IMLTRT | 1 | U1 | QFN-28_EP_6x6_Pitch0.65mm
RF-SHIELD-20X15X4 | 1 | SHIELD1 | Shield1620
SMD ИНД 0402 33 nH ±5% | 1 | L2 | L_0402_5MIL_DWS
SMD ИНД 0402 6.8 nH ±5% | 1 | L3 | L_0402_5MIL_DWS
SMD ИНД 0402 8.2 nH ±0.3nH | 1 | L5 | L_0402_5MIL_DWS
SMD КОНД 0402 1.2 PF +-0.25 PF | 0 | (n.a.) C12 | C_0402_5MIL_DWS
SMD КОНД 0402 100 NF 10% 10VDC | 5 | C3,C4,C5,C6,C20 | C_0402_5MIL_DWS
SMD КОНД 0402 15 PF NP0 | 2 | C1,C2 | C_0402_5MIL_DWS
SMD КОНД 0402 2.2 PF C0G +-0.1PF | 1 | C19 | C_0402_5MIL_DWS
SMD КОНД 0402 33 PF +-0.25 PF | 1 | C9 | C_0402_5MIL_DWS
SMD КОНД 0402 4.2 PF +-0.25pf | 1 | C13 | C_0402_5MIL_DWS
SMD КОНД 0402 4.7 PF C0G 50VDC +/-0.1PF | 1 | C11 | C_0402_5MIL_DWS
SMD КОНД 0402 47 PF C0G 5% 50VDC | 2 | C7,C8 | C_0402_5MIL_DWS
SMD КОНД 0603 22 UF 6.3V | 1 | C10 | C_0603_5MIL_DWS
SMD РЕЗОНАТОР КВАРЦ SMD2016 32.000 Mhz | 1 | X1 | SMD2016_4p
SMD СЪЕДИНИТЕЛ U.FL за GSM антена | 1 | EXT_ANT1 | U.FL-R-SMT-1
ГПП LoRa_RevB | 1

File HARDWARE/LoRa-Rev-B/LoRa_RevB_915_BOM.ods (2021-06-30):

Designation | Quantity | Designator | Package
RF-SHIELD-20X15X4 | 1 | SHIELD1 | Shield1620
SMD СЪЕДИНИТЕЛ U.FL за GSM антена | 1 | EXT_ANT1 | U.FL-R-SMT-1
SMD КОНД 0603 22 UF 6.3V | 1 | C10 | C_0603_5MIL_DWS
SMD ИНД 0402 6.2 nH ±0.3nH | 1 | L5 | L_0402_5MIL_DWS
SMD РЕЗОНАТОР КВАРЦ SMD2016 32.000 Mhz | 1 | X1 | SMD2016_4p
SMD ИС SX1276IMLTRT | 1 | U1 | QFN-28_EP_6x6_Pitch0.65mm
SMD ИНД 0402 10 nH LQP15MN10NG02D | 1 | L4 | L_0402_5MIL_DWS
SMD ИНД 0402 6.8 nH ±5% | 1 | L3 | L_0402_5MIL_DWS
SMD ИНД 0402 33 nH ±5% | 1 | L2 | L_0402_5MIL_DWS
SMD КОНД 0402 47 PF C0G 5% 50VDC | 2 | C7,C8 | C_0402_5MIL_DWS
SMD КОНД 0402 100 NF 10% 10VDC | 5 | C3,C4,C5,C6,C20 | C_0402_5MIL_DWS
SMD КОНД 0402 2.2 PF C0G +-0.1PF | 1 | C19 | C_0402_5MIL_DWS
SMD КОНД 0402 1.8 PF +-0.25pf | 1 | C13 | C_0402_5MIL_DWS
SMD КОНД 0402 1.2 PF +-0.25 PF | 1 | C12 | C_0402_5MIL_DWS
SMD КОНД 0402 4.7 PF C0G 50VDC +/-0.1PF | 1 | C11 | C_0402_5MIL_DWS
SMD КОНД 0402 33 PF +-0.25 PF | 1 | C9 | C_0402_5MIL_DWS
SMD КОНД 0402 15 PF NP0 | 2 | C1,C2 | C_0402_5MIL_DWS
ГПП LoRa_RevB | 1

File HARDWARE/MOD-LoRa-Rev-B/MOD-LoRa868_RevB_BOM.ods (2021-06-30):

Designation | Quantity | Designator | Package
SMD ИНД 0402 6.8 nH ±5% | 1 | L3 | L_0402_5MIL_DWS
SMD КОНД 0402 15 PF NP0 | 2 | C1,C2 | C_0402_5MIL_DWS
SMD КОНД 0402 33 PF +-0.25 PF | 1 | C9 | C_0402_5MIL_DWS
SMD КОНД 0603 22 UF 6.3V | 1 | C10 | C_0603_5MIL_DWS
SMD СЪЕДИНИТЕЛ U.FL | 1 | EXT_ANT1 | U.FL-R-SMT-1
IDC10S | 1 | CON1 | UEXTF
RF-SHIELD-20X15X4 | 1 | SHIELD1 | Shield1620
SMD ИНД 0402 10 nH LQP15MN10NG02D | 1 | L4 | L_0402_5MIL_DWS
SMD ИНД 0402 33 nH ±5% | 1 | L2 | L_0402_5MIL_DWS
SMD ИНД 0402 8.2 nH ±0.3nH | 1 | L5 | L_0402_5MIL_DWS
SMD ИС SX1276IMLTRT | 1 | U1 | QFN-28_EP_6x6_Pitch0.65mm
SMD КОНД 0402 1.2 PF +-0.25pf | 1 | C12 | C_0402_5MIL_DWS
SMD КОНД 0402 4.2 PF +-0.25pf | 1 | C13 | C_0402_5MIL_DWS
SMD КОНД 0402 100 NF 10% 10VDC | 5 | C3,C4,C5,C6,C20 | C_0402_5MIL_DWS
SMD КОНД 0402 2.2 PF C0G +-0.1PF | 1 | C19 | C_0402_5MIL_DWS
SMD КОНД 0402 4.7 PF C0G 50VDC +/-0.1PF | 1 | C11 | C_0402_5MIL_DWS
SMD КОНД 0402 47 PF C0G 5% 50VDC | 2 | C7,C8 | C_0402_5MIL_DWS
SMD РЕЗОНАТОР КВАРЦ SMD2016 32.000 Mhz | 1 | X1 | SMD2016_4p
ГПП MOD-LoRa_RevB | 1

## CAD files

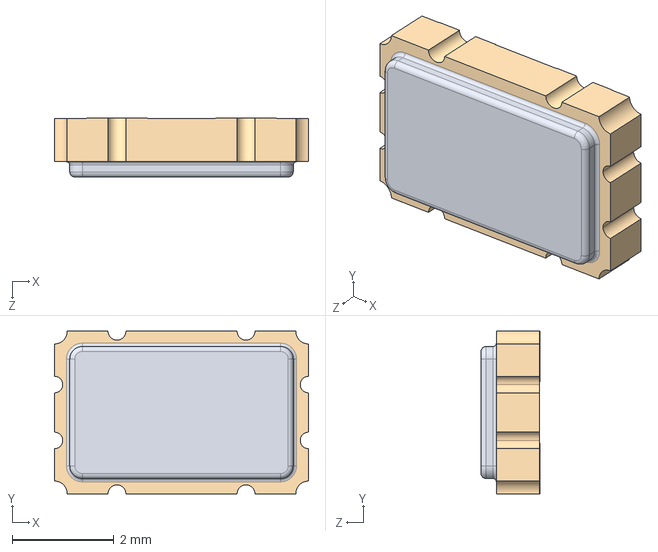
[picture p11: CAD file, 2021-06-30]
HARDWARE/LoRa-Rev-B/3d/QSG5032.step
5.00 x 3.20 x 1.16 mm

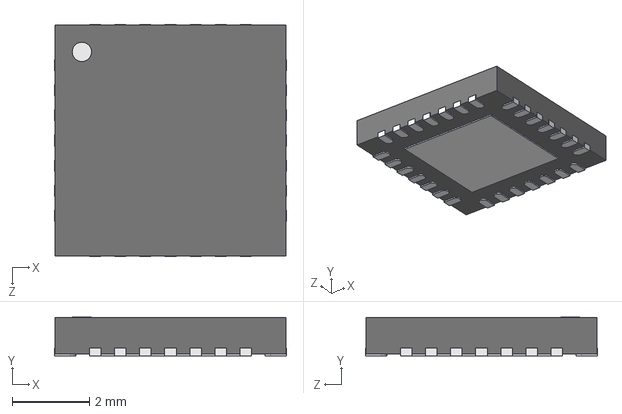
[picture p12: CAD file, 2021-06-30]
HARDWARE/LoRa-Rev-B/3d/QFN-28(6.0x6.0x1.0mm_P0.65mm).STEP
6.02 x 1.00 x 6.02 mm

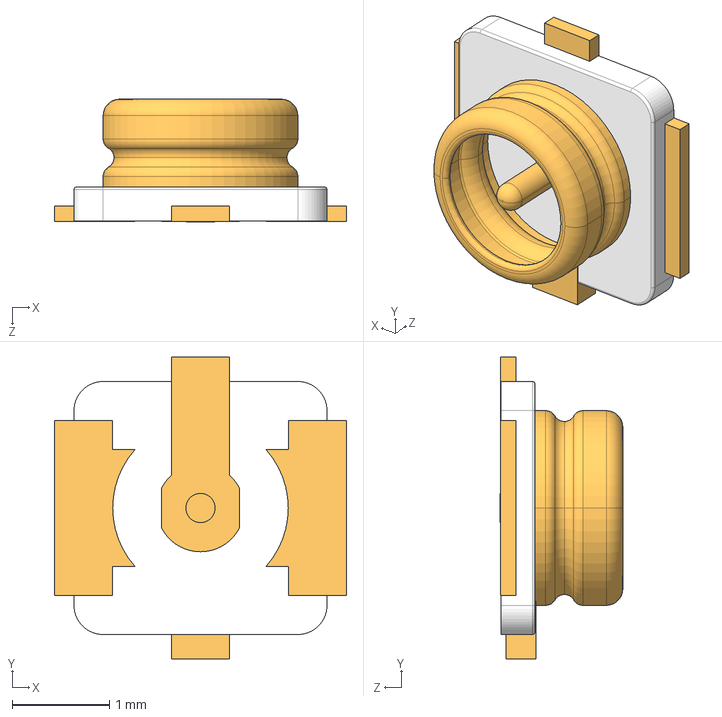
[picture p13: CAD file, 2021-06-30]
HARDWARE/LoRa-Rev-B/3d/U_FL-R-SMT-1.step
3.00 x 3.10 x 1.26 mm

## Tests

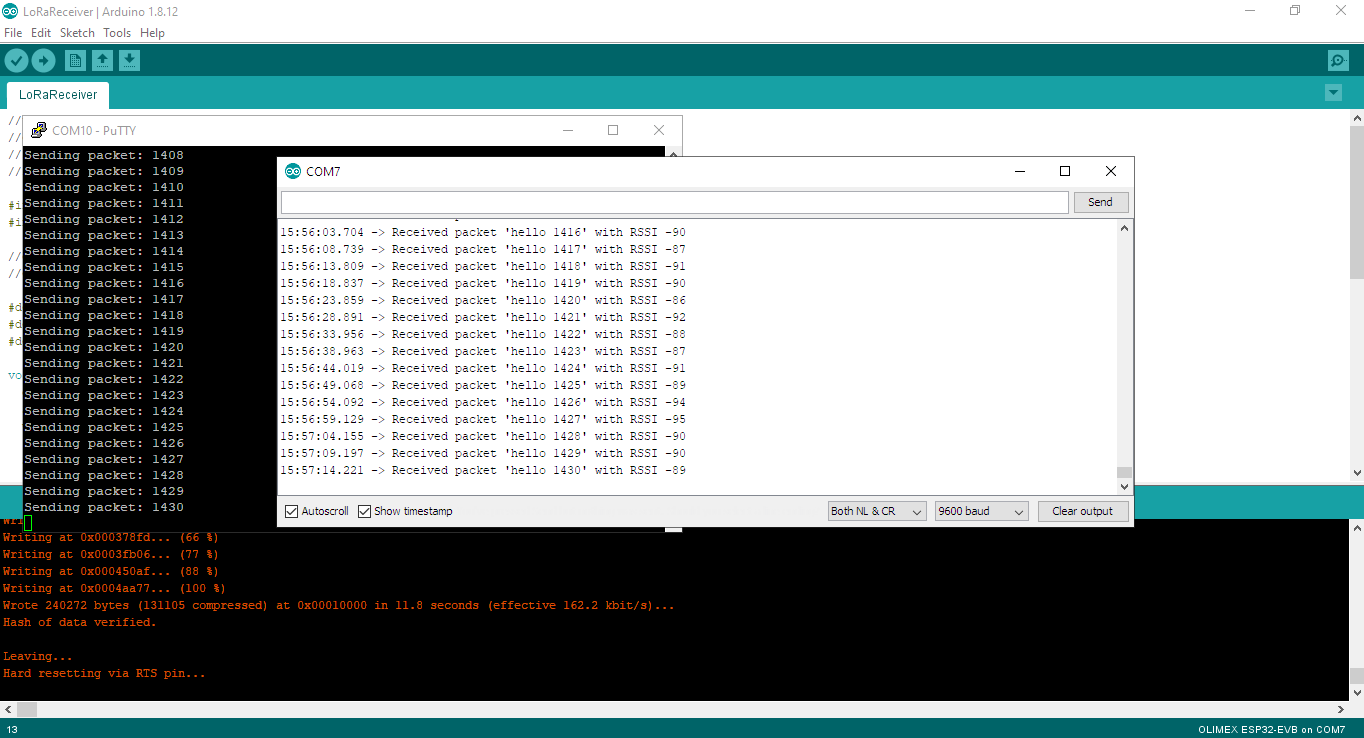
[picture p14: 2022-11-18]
SOFTWARE/Arduino/Send-receive-demo/test.png

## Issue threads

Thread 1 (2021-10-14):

wrong pin order CON1 in schematic and silk screen

feuera, 2021-10-14:
In schematic and datasheet con1 has 1-1 and 8-8 mapping. In kicad pcb files and real world the pin mapping for con1 is reversed.

nonsintetic, 2022-02-03:
Can confirm.. just bought 5 `LoRa868-ANT` boards (the small one, not `MOD-LoRa868`) and the pinout for CON1 is *indeed reversed* in all the documentation except the KiCAD file. The documentation and everything here is for Rev_B, but the board I received is Rev_A, couldn't find anything for that, maybe they just didn't finish updating everything.

Guess I have to throw away the custom PCBs i had made. I'm normally a big Olimex fan, but they really dropped the ball on this one. This issue is from 2021, over a year ago, it's just 2 PDF files to fix.

I have the `MOD-LoRa868`, for that one the pinout in the PDF is correct.

DanKoloff, 2022-02-14:
Thanks for the notice, sorry for the delay in response I somehow missed it, please in future use olimex@support.com for such hardware or design related issues.

Sorry for the experience. It appears the designers made a mistake and there is no consistency between schematic, labelling, and PCB. White print is wrong. I will suggest to the team to swap 1 and 8 labels near CON1 in next revision.

> The documentation and everything here is for Rev_B, but the boards I received are all Rev_A, couldn't find anything for that, maybe they just didn't finish updating everything.

This part is the same for revision A and revision B. It is wrong in both schematics.

DanKoloff, 2022-02-16:
Edited the schematic and the document. Now should be easier to notice the routing and naming. Will close this issue, if you notice other discrepancy please either open a new issue or better contact us at support@olimex.com

Closed 2022-02-16.

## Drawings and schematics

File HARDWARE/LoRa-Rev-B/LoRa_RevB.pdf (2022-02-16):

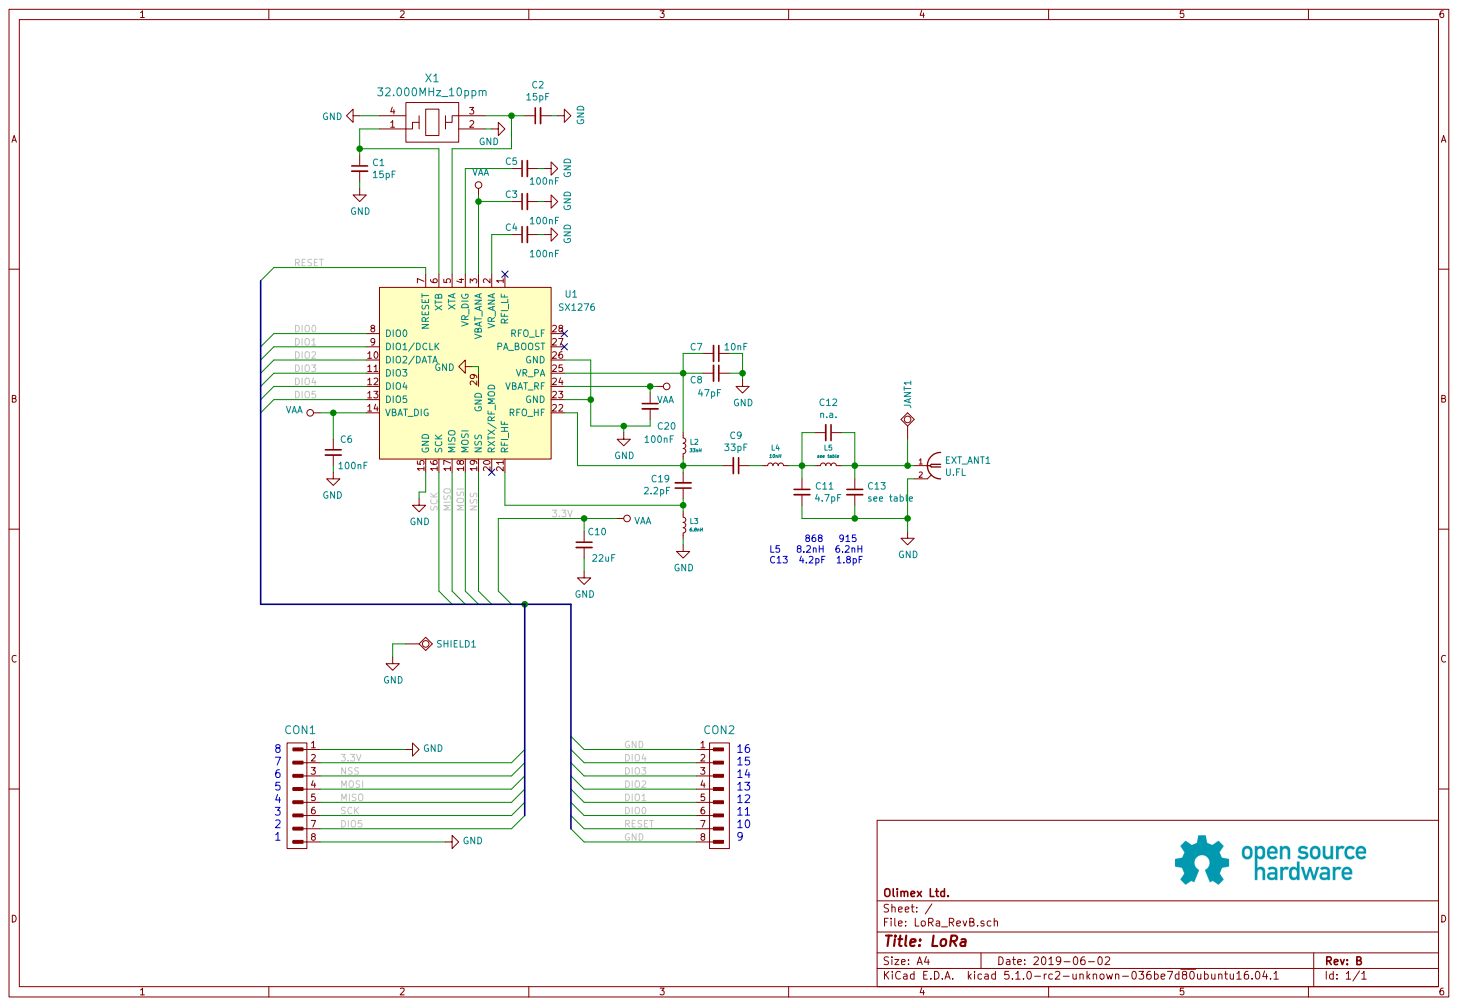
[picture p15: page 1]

1 DIO2/DATA 10 DIO3 11 DIO4 12 DIO5 13 VBAT_DIG 14 GND 15 SCK 16 MISO 17 MOSI 18 NSS 19 VR_ANA

2 RXTX/RF_MOD 20 RFI_HF 21 RFO_HF 22 GND 23 VBAT_RF 24 VR_PA 25 GND 26 PA_BOOST 27 RFO_LF 28 GND 29 VBAT_ANA
File: LoRa_RevB.sch Sheet: / Olimex Ltd. RFI_LF

8 CON1 GND GND 3 | 3

3.3V 4 | GND 4

7 DIO5 | RESET 7

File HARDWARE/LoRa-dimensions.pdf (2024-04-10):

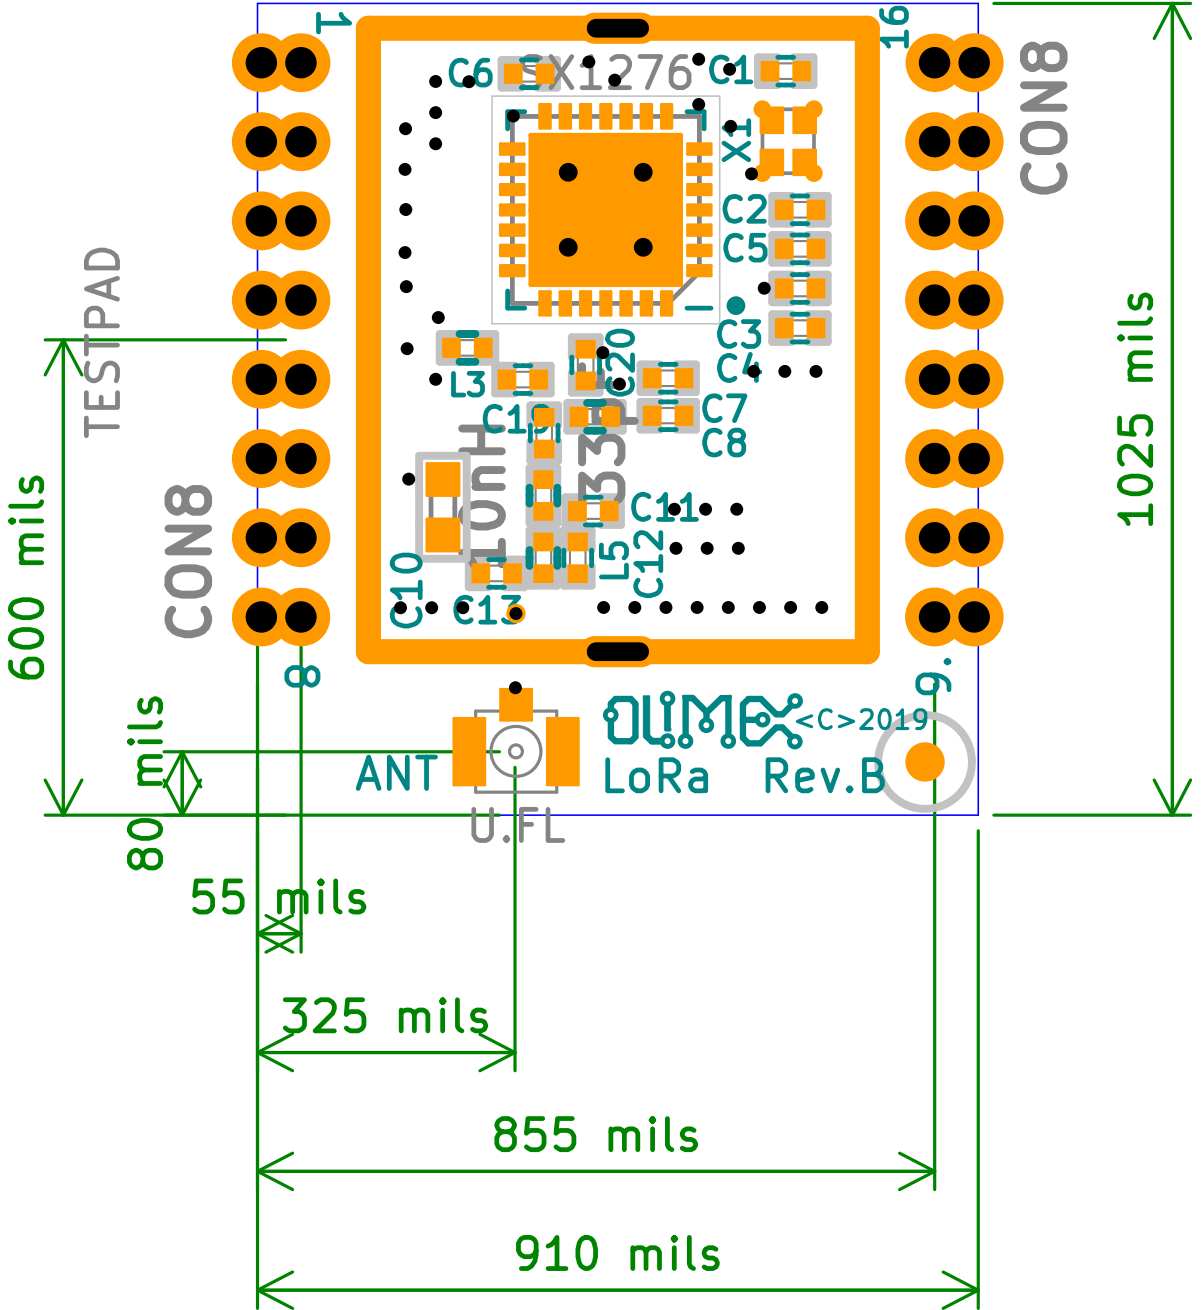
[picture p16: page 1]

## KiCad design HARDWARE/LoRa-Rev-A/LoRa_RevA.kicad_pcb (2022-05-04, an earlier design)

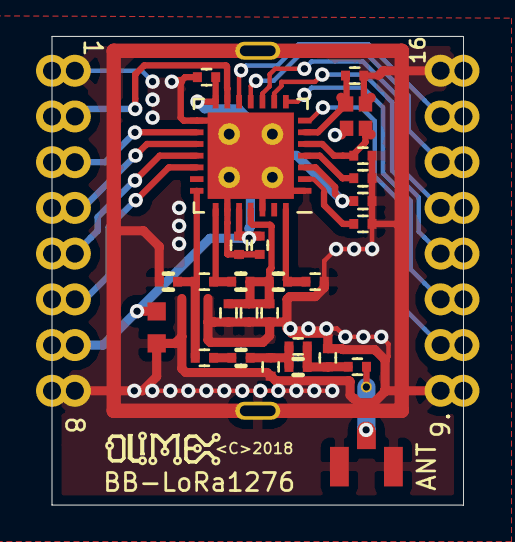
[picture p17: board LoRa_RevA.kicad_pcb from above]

Board: 2 copper layers, 22.9 x 26.0 mm, 31 parts (0 on the bottom side), 25 nets.

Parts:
C1, C2: 15pF; C_0402_5MIL_DWS
C3, C4, C5, C6, C20: 100nF; C_0402_5MIL_DWS
C7, C8, C16, C21: 47pF; C_0402_5MIL_DWS
C9: 33pF; C_0402_5MIL_DWS
C10: 22uF; C_0603_5MIL_DWS
C11: 4.7pF; C_0402_5MIL_DWS
C12: 1.2pF; C_0402_5MIL_DWS
C13: 1.8pF; C_0402_5MIL_DWS
C19: 2.2pF; C_0402_5MIL_DWS
C25: n.a. (2.2pF); C_0402_5MIL_DWS
C36: 10nF; C_0402_5MIL_DWS
CON1, CON2: CON8; HN1x8_EDGE
EXT_ANT1: U.FL; U.FL-R-SMT-1
JANT1: TESTPAD; TP_SMD
L1: n.a. (82nH); L_0402_5MIL_DWS
L2: 33nH; L_0402_5MIL_DWS
L3: 6.8nH; L_0402_5MIL_DWS
L4: 10nH; L_0402_5MIL_DWS
L5: 6.2nH; L_0402_5MIL_DWS
SHIELD1: TESTPAD; Shield1620
U1: SX1276; QFN-28_EP_6x6_Pitch0.65mm
X1: 32.000MHz_10ppm; SMD2016_4p

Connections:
/DIO0: CON2.6, U1.8
/DIO1: CON2.5, U1.9
/DIO2: CON2.4, U1.10
/DIO3: CON2.3, U1.11
/DIO4: CON2.2, U1.12
/DIO5: CON1.7, U1.13
/MISO: CON1.5, U1.17
/MOSI: CON1.4, U1.18
/NSS: CON1.3, U1.19
/RESET: CON2.7, U1.7
/SCK: CON1.6, U1.16
GND: C1.2, C2.2, C3.2, C4.2, C5.2, C6.2, C7.1, C8.1, C10.2, C11.2, C13.2, C20.2, C21.2, C25.1, C36.2, CON1.1, CON1.8, CON2.1, CON2.8, EXT_ANT1.2, L3.1, SHIELD1.1, U1.1, U1.15, U1.23, U1.26, U1.29, X1.2, X1.4
unnamed: C1.1, U1.6, X1.1
unnamed: C2.1, U1.5, X1.3
unnamed: C4.1, U1.2
unnamed: C5.1, U1.4
unnamed: C9.1, L4.1
unnamed: C11.1, C12.2, L4.2, L5.1
unnamed: C12.1, C13.1, C16.2, L5.2
unnamed: C16.1, EXT_ANT1.1, JANT1.1
unnamed: C9.2, C19.1, L3.2, U1.21
unnamed: C19.2, L2.1, U1.22
unnamed: C25.2, L1.1, U1.28
unnamed: C7.2, C8.2, C36.1, L1.2, L2.2, U1.25
VAA: C3.1, C6.1, C10.1, C20.1, C21.1, CON1.2, U1.3, U1.14, U1.24

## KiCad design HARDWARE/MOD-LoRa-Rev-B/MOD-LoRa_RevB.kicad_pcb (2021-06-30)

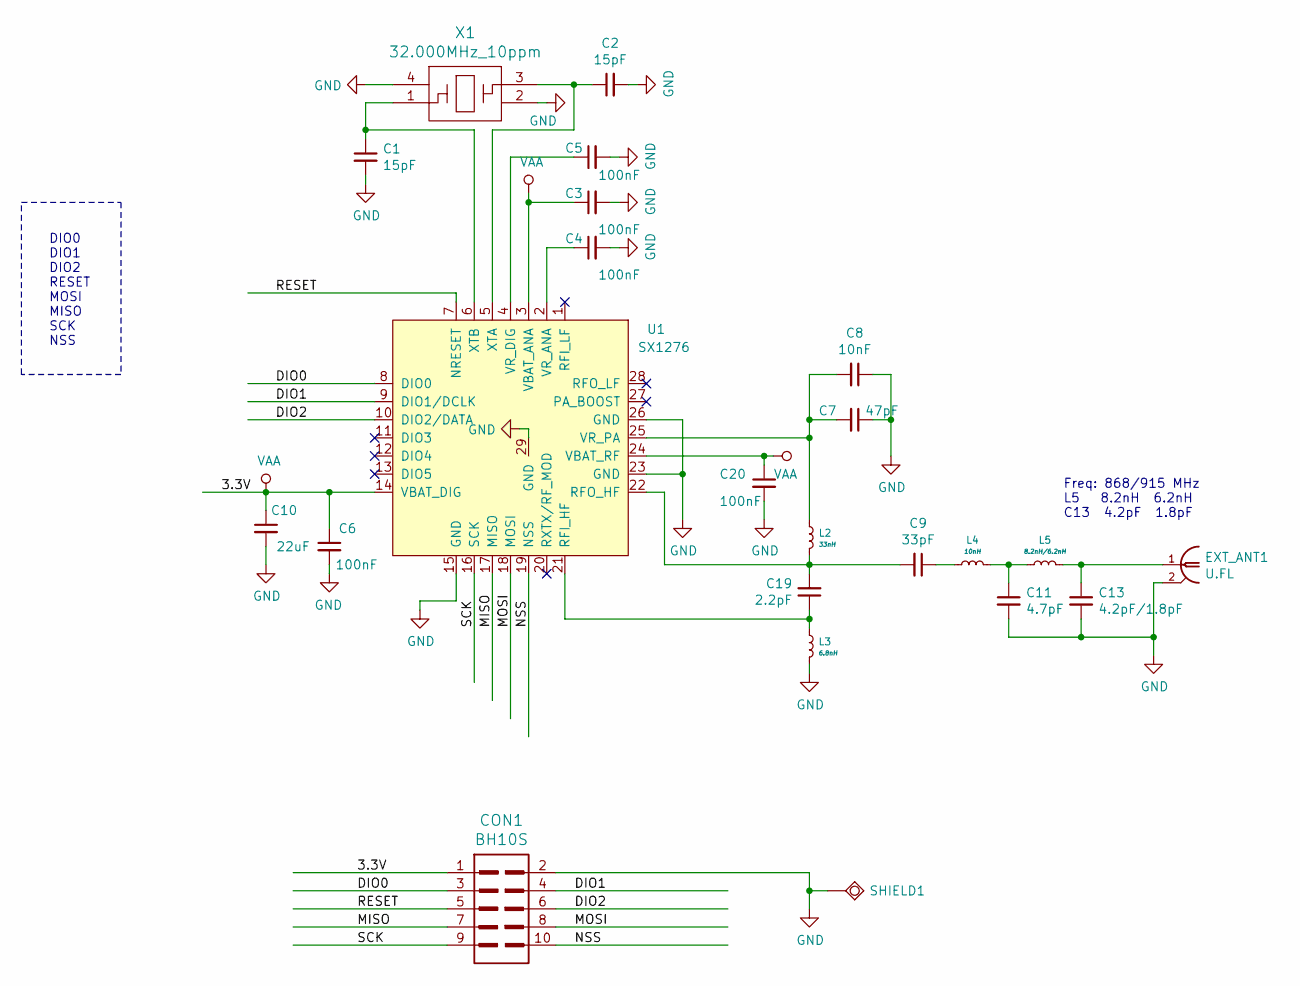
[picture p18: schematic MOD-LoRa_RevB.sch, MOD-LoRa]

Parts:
C1, C2: 15pF; C_0402_5MIL_DWS
C3, C4, C5, C6, C20: 100nF; C_0402_5MIL_DWS
C7: 47pF; C_0402_5MIL_DWS
C8: 10nF; C_0402_5MIL_DWS
C9: 33pF; C_0402_5MIL_DWS
C10: 22uF; C_0603_5MIL_DWS
C11: 4.7pF; C_0402_5MIL_DWS
C13: 4.2pF/1.8pF; C_0402_5MIL_DWS
C19: 2.2pF; C_0402_5MIL_DWS
CON1: BH10S; UEXTF
EXT_ANT1: U.FL; U.FL-R-SMT-1
L2: 33nH; L_0402_5MIL_DWS
L3: 6.8nH; L_0402_5MIL_DWS
L4: 10nH; L_0402_5MIL_DWS
L5: 8.2nH/6.2nH; L_0402_5MIL_DWS
SHIELD1: TESTPAD; Shield1620
U1: SX1276; QFN-28_EP_6x6_Pitch0.65mm
X1: 32.000MHz_10ppm; SMD2016_4p

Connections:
/DIO0: CON1.3, U1.8 (DIO0)
/DIO1: CON1.4, U1.9 (DIO1/DCLK)
/DIO2: CON1.6, U1.10 (DIO2/DATA)
/MISO: CON1.7, U1.17 (MISO)
/MOSI: CON1.8, U1.18 (MOSI)
/NSS: CON1.10, U1.19 (NSS)
/RESET: CON1.5, U1.7 (NRESET)
/SCK: CON1.9, U1.16 (SCK)
GND: C1.2, C2.2, C3.2, C4.2, C5.2, C6.2, C7.1, C8.1, C10.2, C11.2, C13.2, C20.2, CON1.2, EXT_ANT1.2, EXT_ANT1.3, EXT_ANT1.4, EXT_ANT1.5, L3.1, SHIELD1.1, U1.15 (GND), U1.23 (GND), U1.26 (GND), U1.29 (GND), X1.2, X1.4
unnamed: C1.1, U1.6 (XTB), X1.1
unnamed: C2.1, U1.5 (XTA), X1.3
unnamed: C4.1, U1.2 (VR_ANA)
unnamed: C5.1, U1.4 (VR_DIG)
unnamed: C7.2, C8.2, L2.2, U1.25 (VR_PA)
unnamed: C9.1, L4.1
unnamed 15: C11.1, L4.2, L5.1; also elsewhere on the board
unnamed 16: C13.1, EXT_ANT1.1, L5.2; also elsewhere on the board
unnamed: C19.1, L3.2, U1.21 (RFI_HF)
unnamed: C9.2, C19.2, L2.1, U1.22 (RFO_HF)
VAA: C3.1, C6.1, C10.1, C20.1, CON1.1, U1.3 (VBAT_ANA), U1.14 (VBAT_DIG), U1.24 (VBAT_RF)

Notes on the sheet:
DIO0 DIO1 DIO2 RESET MOSI MISO SCK NSS
Freq: 868/915 MHz L5 8.2nH 6.2nH C13 4.2pF 1.8pF

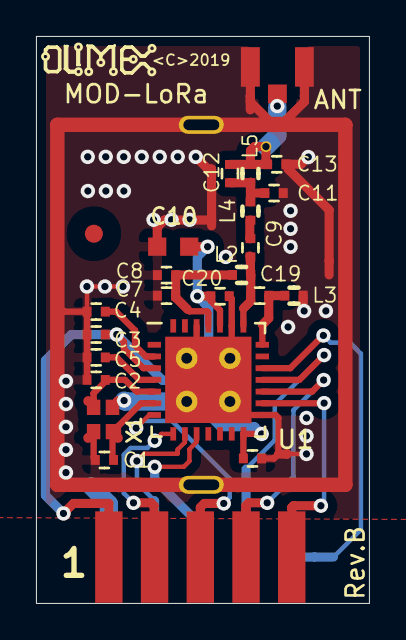
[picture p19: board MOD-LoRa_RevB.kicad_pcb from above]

Board: 2 copper layers, 18.5 x 31.5 mm, 26 parts (0 on the bottom side), 20 nets.

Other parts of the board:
C12: 1.2pF; C_0402_5MIL_DWS
JANT1: TESTPAD; TP_SMD
Ref*: Val**; Fiducial1x3_transp

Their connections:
unnamed 15: C12.2; also elsewhere on the board
unnamed 16: C12.1, JANT1.1; also elsewhere on the board

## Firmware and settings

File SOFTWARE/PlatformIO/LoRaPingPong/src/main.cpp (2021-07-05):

#include <Arduino.h>
#include <SPI.h>              // include libraries
#include <LoRa.h>

#define FREQUENCY 867900000
//#define FREQUENCY 915200000

//#define FREQUENCY 868500000

//#define leonardo

#ifdef megaatmega2560
const int csPin = 53;          // LoRa radio chip select
const int resetPin = 21;       // LoRa radio reset
const int irqPin = 18;         // change for your board; must be a hardware interrupt pin
#endif

#ifdef leonardo
const int csPin = 13;          // LoRa radio chip select
const int resetPin = 3;       // LoRa radio reset
const int irqPin = 1;         // change for your board; must be a hardware interrupt pin
#endif



long lastSendTime = 0;        // last send time
int interval = 2000;          // interval between sends

void setup() {
  // put your setup code here, to run once:

#ifdef leonardo
  pinMode(8, OUTPUT);
  digitalWrite(8, 0);

  pinMode(7,OUTPUT);
  digitalWrite(7,0);
  pinMode(9,OUTPUT);
  digitalWrite(9,0);
  delay(100);

  pinMode(8,OUTPUT);
  digitalWrite(8,0);
  delay(100);

#endif
  Serial.begin(115200);                   // initialize serial
  while (!Serial);

  Serial.println("LoRa Ping-Pong");

  // override the default CS, reset, and IRQ pins (optional)
  LoRa.setPins(csPin, resetPin, irqPin);// set CS, reset, IRQ pin

  if (!LoRa.begin(FREQUENCY)) {             // initialize ratio at 915 MHz
    Serial.println("LoRa init failed. Check your connections.");
    while (true);                       // if failed, do nothing
  }
	LoRa.setSignalBandwidth(125E3);
	LoRa.setSpreadingFactor(10);

 // LoRa.setSignalBandwidth(125E3);
	//LoRa.setSpreadingFactor(12);
	LoRa.setTxPower(14,0);
  Serial.println("LoRa init succeeded.");
  interval = random(14000) + 1000;    // 2-3 seconds
}


void sendMessage(String outgoing) {
  LoRa.beginPacket();                   // start packet
  //LoRa.write(outgoing.length());        // add payload length
  LoRa.print(outgoing);                 // add payload
  LoRa.endPacket();                     // finish packet and send it
}

void onReceive(int packetSize) {
  if (packetSize == 0) return;          // if there's no packet, return

  String incoming = "";

  while (LoRa.available()) {
    incoming += (char)LoRa.read();
  }

  if (incoming == "PING")
  { 
    String message = "PONG";   // send a message
    sendMessage(message);
    Serial.println("Sending Echo " + message);
    lastSendTime = millis();            // timestamp the message
    interval = random(14000) + 1000;    // 15 seconds

  }
  // if message is for this device, or broadcast, print details:
  Serial.println("Message: " + incoming);
  Serial.println("RSSI: " + String(LoRa.packetRssi()));
  Serial.println("Snr: " + String(LoRa.packetSnr()));
  Serial.println();
  
}

void loop() {
  // put your main code here, to run repeatedly:
   if (millis() - lastSendTime > interval) {
    String message = "PING";   // send a message
    sendMessage(message);
    Serial.println("Sending " + message);
    lastSendTime = millis();            // timestamp the message
    interval = random(4000) + 1000;    // 2-3 seconds
  }

  // parse for a packet, and call onReceive with the result:
  onReceive(LoRa.parsePacket());
}

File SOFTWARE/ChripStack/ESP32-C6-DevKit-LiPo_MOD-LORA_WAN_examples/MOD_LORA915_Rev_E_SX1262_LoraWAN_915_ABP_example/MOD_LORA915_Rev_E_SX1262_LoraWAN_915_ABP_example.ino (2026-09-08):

/*
 * RA-01SH (SX1262) LoRaWAN ABP Test — ESP32 — US915
 * ==================================================
 *
 * Production test for the RA-01SH module (SX1262 chip) with
 * LoRaWAN 1.0.3 ABP activation on the US915 band, sub-band 2
 * (channels 8-15 + 500kHz channel 65 — matches an 8-channel
 * gateway listening on 903.9-905.3 MHz).
 *
 * Two board-specific fixes are included:
 *
 * 1. Over-Current Protection (OCP) correction. RadioLib's chip
 *    detection reports this module's VERSION_STRING as "SX1261"
 *    (a cosmetic mismatch - the physical chip is SX1262), which
 *    leads to the OCP register defaulting to the lower SX1261
 *    limit (0x18, ~60 mA - enough for only about +15 dBm) instead
 *    of the correct SX1262 default (0x38, ~140 mA, required for
 *    the full +22 dBm HP PA output). Without this correction, the
 *    requested TX power is accepted and the PA is configured for
 *    it, but the actual RF output is silently current-limited to
 *    roughly +12-15 dBm regardless of the requested power
 *    (confirmed with a powermeter on this board).
 *
 * 2. Self-healing data rate bootstrap. On a fresh session, the
 *    network server sends an initial batch of MAC commands
 *    (channel mask setup, ADR parameters, RX timing, etc.). The
 *    device's replies to that batch, combined with any
 *    application payload, can exceed the US915 DR0 dwell-time
 *    payload limit (11 bytes). This sketch temporarily raises the
 *    data rate for the first few uplinks after a fresh session,
 *    then automatically drops back to DR0 (maximum range) once
 *    the MAC command queue has settled — and remembers that state
 *    across reboots, so a normal power-cycle does not repeat the
 *    bootstrap.
 *
 * Libraries: RadioLib, Preferences (ESP32 core)
 */

#include <RadioLib.h>
#include <Preferences.h>
#include <esp_task_wdt.h>

// ───────────────────────── Pins ─────────────────────────
#define LORA_NSS    8
#define LORA_BUSY   5
#define LORA_DIO1   4
#define LORA_RST    RADIOLIB_NC   // no hardware reset - see XTAL note below
#define LORA_SCK    0
#define LORA_MISO   14
#define LORA_MOSI   1
#define BUTTON_PIN  9
#define LED_PIN     15

#define TX_POWER    22   // dBm - SX1262 hardware maximum (HP PA).
                          // Requires the OCP correction below to
                          // actually reach full output on this
                          // board - see initRadio().

// ─────────────────── US915 sub-band ────────────────────
// US915 has 8 sub-bands (64 channels total). Most 8-channel
// gateways listen on only one sub-band. RadioLib numbers
// sub-bands starting from 1; sub-band 2 activates channels 8-15
// (903.9-905.3 MHz) plus the matching 500kHz channel 65
// (904.6 MHz). Verify this value against your gateway's channel
// plan before deploying to a different gateway.
#define US915_SUBBAND   2

// ───────────── Self-healing data rate bootstrap ─────────────
// FINAL_DR is the normal operating data rate (DR0 = SF10/BW125,
// the maximum spreading factor allowed on US915's 125kHz channels
// and therefore the maximum-range setting for this band).
// BOOTSTRAP_DR is used temporarily after a fresh session, where
// its higher dwell-time payload limit safely absorbs the
// network's initial MAC command batch and the device's replies
// to it. BOOTSTRAP_UPLINKS is how many uplinks are sent at
// BOOTSTRAP_DR before switching back.
#define FINAL_DR            0
#define BOOTSTRAP_DR         1
#define BOOTSTRAP_UPLINKS   3

// ─────────────────── Frequency correction ────────────────────
// SX126x chips with a plain XTAL crystal (not TCXO) can have a
// systematic frequency error, depending on the crystal's load
// capacitance. This error is proportional (ppm-based) to the
// carrier frequency, so a value calibrated at one band does NOT
// carry over directly to another — it must be re-measured for
// each operating frequency.
//
// Calibrate by comparing the requested frequency against the
// actual measured frequency (e.g. via the gateway's 'foff' log)
// until the residual offset drops to a few hundred Hz.
#define FREQ_CORRECTION_HZ   (0.0f)

// ────────────────── LoRaWAN ABP credentials ─────────────────
uint32_t devAddr     = 0x01020304;
uint8_t  nwkSKey[]   = {0xFE, 0xEF, 0x06, 0x0B, 0xDF, 0xA4, 0xBA, 0x3C,
                        0x84, 0x82, 0xA2, 0xBA, 0x70, 0xAA, 0x2F, 0x37};
uint8_t  appSKey[]   = {0xFE, 0xEF, 0x06, 0x0B, 0xDF, 0xA4, 0xBA, 0x3C,
                        0x84, 0x82, 0xA2, 0xBA, 0x70, 0xAA, 0x2F, 0x37};

// ───────────────── Test retry settings ───────────────
#define MAX_ATTEMPTS       3      // confirmed uplink attempts before reporting failure
#define RETRY_DELAY_MS     2000   // delay between attempts

// ───────────────────────────────────────────────────────────
// Override of setFrequency() so the frequency correction is
// applied to every call made by the LoRaWAN stack — TX, RX1 and
// RX2 — without touching RadioLib itself. setFrequency() is
// declared virtual in SX126x/PhysicalLayer, so the override
// applies automatically everywhere the stack calls it through a
// polymorphic pointer.
class SX1262Corrected : public SX1262 {
  public:
    SX1262Corrected(Module* mod) : SX1262(mod) {}

    int16_t setFrequency(float freq) override {
      return SX1262::setFrequency(freq + (FREQ_CORRECTION_HZ / 1e6f));
    }
};

SX1262Corrected radio = new Module(LORA_NSS, LORA_DIO1, LORA_RST, LORA_BUSY);
LoRaWANNode      node(&radio, &US915, US915_SUBBAND);

// ─────────────────── NVS session persistence ──────────────
// Frame counters must survive a board reset, otherwise the
// network server will reject subsequent uplinks as a replay
// attack. The "settled" flag remembers whether the initial MAC
// command bootstrap has already completed, so a normal power
// cycle does not repeat it.
Preferences store;
uint8_t nonceBuf[RADIOLIB_LORAWAN_NONCES_BUF_SIZE];
uint8_t sessionBuf[RADIOLIB_LORAWAN_SESSION_BUF_SIZE];

uint32_t testCounter    = 0;
bool     macSettled     = false;
uint8_t  bootstrapCount = 0;

void saveSession() {
  store.begin("lora", false);
  store.putBytes("nonces",  node.getBufferNonces(),  RADIOLIB_LORAWAN_NONCES_BUF_SIZE);
  store.putBytes("session", node.getBufferSession(), RADIOLIB_LORAWAN_SESSION_BUF_SIZE);
  store.end();
  Serial.print(F("  Session saved, fCntUp: "));
  Serial.println(node.getFCntUp());
}

void saveMacSettled(bool settled) {
  store.begin("lora", false);
  store.putBool("settled", settled);
  store.end();
}

void clearSession() {
  store.begin("lora", false);
  store.clear();
  store.end();
  Serial.println(F("\n  WARNING: NVS session cleared! Restart the board.\n"));
}

// ───────────────────────── Helpers ─────────────────────────
void printSeparator() {
  Serial.println(F("========================================"));
}
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

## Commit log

2021-06-30 upload KiCad and User Manual
    [LoRa_RevB-B_Cu.gbr, LoRa_RevB-B_Mask.gbr, LoRa_RevB-B_SilkS.gbr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]
2022-05-04 Update
    Added revision A files
    [LoRa_RevA.kicad_pcb, LoRa_RevA.sch, LoRa_RevA_868_BOM.ods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]
2023-10-10 LoRa examples update
    Fixed the issue with the limited range of communication between sender and receiver modules.
    [LoRaReceiver.ino, LoRaSender.ino]
2026-09-08 Fix
    Added demo codes required by ESP32-C6-DevKit-LiPo
    [MOD-LORA868_Rev_E-SX1262_LoraWAN_868_ABP_example.ino, MOD_LORA915_Rev_E_SX1262_LoraWAN_915_ABP_example.ino, mod-lora868_Rev_C_SX1276-ABP-rfo-Rpi-LR1302-chirpst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]
